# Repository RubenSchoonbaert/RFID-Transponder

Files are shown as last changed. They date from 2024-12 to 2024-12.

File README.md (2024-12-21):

# RFID-Transponder



Overview

This project is a compact and versatile PCB design featuring an RFID/NFC tag IC. It includes components for writing and managing data on the RFID tag, modern power input options, and flexible microcontroller integration.
Key Features

    RFID/NFC Tag Functionality
        Built-in RFID coil, designed using eDesignSuite by ST-Engineering.
        Integrated with the ST25DV04KC RFID/NFC Tag IC, offering:
            16 KB EEPROM for data storage.
            Communication via the I2C bus.
        Data can be written to the tag using external devices, such as smartphones with RFID capabilities.

    Data Storage Support
        Includes a Micro SD card slot for additional data storage.
        Utilizes a 74LVC125 IC for safe voltage level shifting between the 5V logic of the microcontroller and the 3.3V logic of the Micro SD card.

    Power Input
        Powered via a USB-C port delivering 5V.
        Configured with 1 kΩ resistors on the CC pins to ensure USB-C standard compliance.

    Flexible Microcontroller Integration
        Designed around the AtmegaXX08 series of microcontrollers, specifically the Atmega3208.
        Compatible with other ICs in the same series and package.

    Connectivity
        Provides connectors for UPDI and UART for programming and debugging.
        Optional GPIO breakout for additional interfacing needs.

Applications

    Use as an RFID/NFC tag in systems requiring dynamic, writable RFID data storage.
    Embedded designs requiring compact, integrated EEPROM and I2C functionality.
    Systems needing programmable and customizable tag IC solutions.

Schematic



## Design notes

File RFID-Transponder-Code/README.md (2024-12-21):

Application Note for RFID Transponder source code
Overview

This application demonstrates the integration of an ST25DV NFC/RFID Tag IC, an SD card module, and an Arduino-compatible microcontroller. It provides functionality for reading and writing data to the RFID tag, managing records on an SD card, and testing the system's integrated components such as LEDs and a piezo buzzer.
Features

    RFID Tag Management:
        Write a record to the ST25DV RFID Tag IC.
        Clear the last RFID entry.
        Detect new records from the RFID tag and log them on the SD card.

    SD Card Integration:
        Store and retrieve records from a text file (records.txt).
        Check for duplicate records before saving.
        Clear all records on the SD card.

    System Testing:
        Test the onboard piezo buzzer with preprogrammed melodies.
        Test the LED with blink functionality.

    Command Interface:
        Interactive commands via Serial Monitor for managing RFID and SD card operations.

Command Reference

    $printFile
    Prints all records stored on the SD card.

    $clearFile
    Clears all records in records.txt on the SD card.

    $clearRFID
    Writes a placeholder (!ignore) to the RFID tag to clear its last entry.

    $addRecord <record>
    Adds a new record to both the RFID tag and the SD card.

    $testBuzzer
    Plays a short melody on the piezo buzzer.

    $testLED
    Blinks the onboard LED to verify functionality.

System Workflow

    Setup:
        Initializes the ST25DV RFID Tag IC and the SD card module.
        Displays a splash screen with available commands.

    Serial Commands:
        Waits for user input via Serial Monitor.
        Executes the corresponding command and provides feedback through Serial output and the buzzer/LED.

    RFID Reading:
        Continuously reads the URI stored on the RFID tag.
        If a new record is detected and is not a duplicate, logs it to the SD card.

    Data Logging:
        Uses the SD card to store a persistent record of RFID tag data.
        Ensures duplicate records are not logged to prevent redundancy.

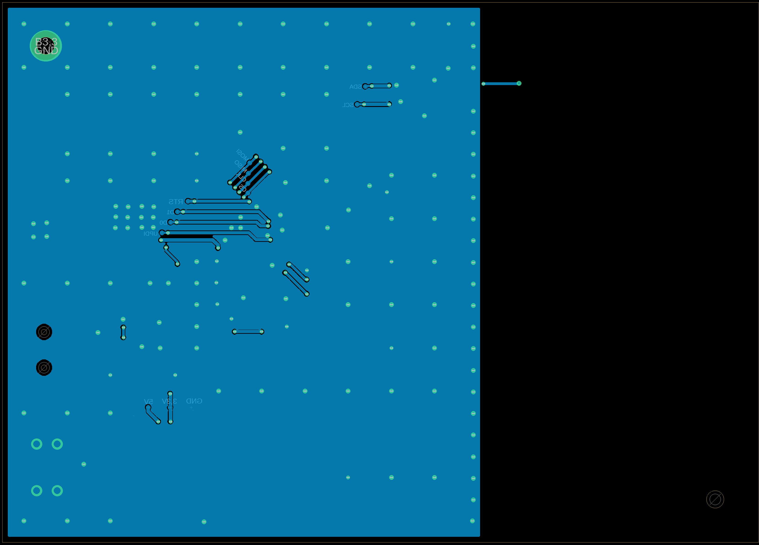
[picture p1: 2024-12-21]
RFID_Transponder/Bot-WP.png

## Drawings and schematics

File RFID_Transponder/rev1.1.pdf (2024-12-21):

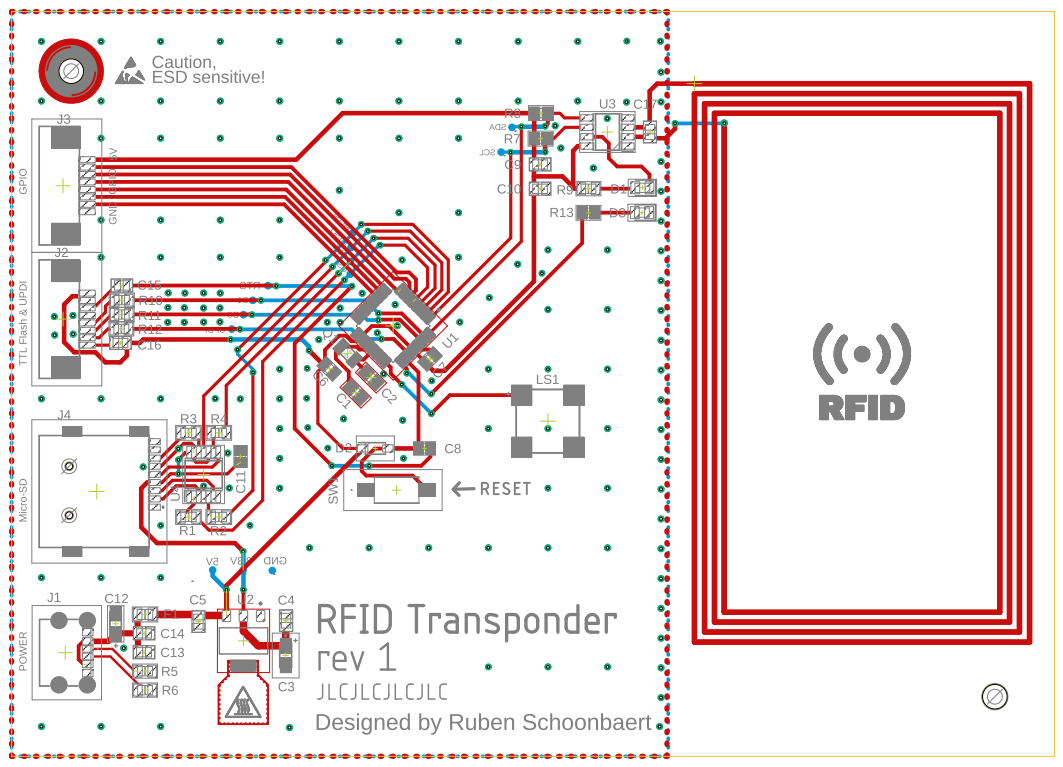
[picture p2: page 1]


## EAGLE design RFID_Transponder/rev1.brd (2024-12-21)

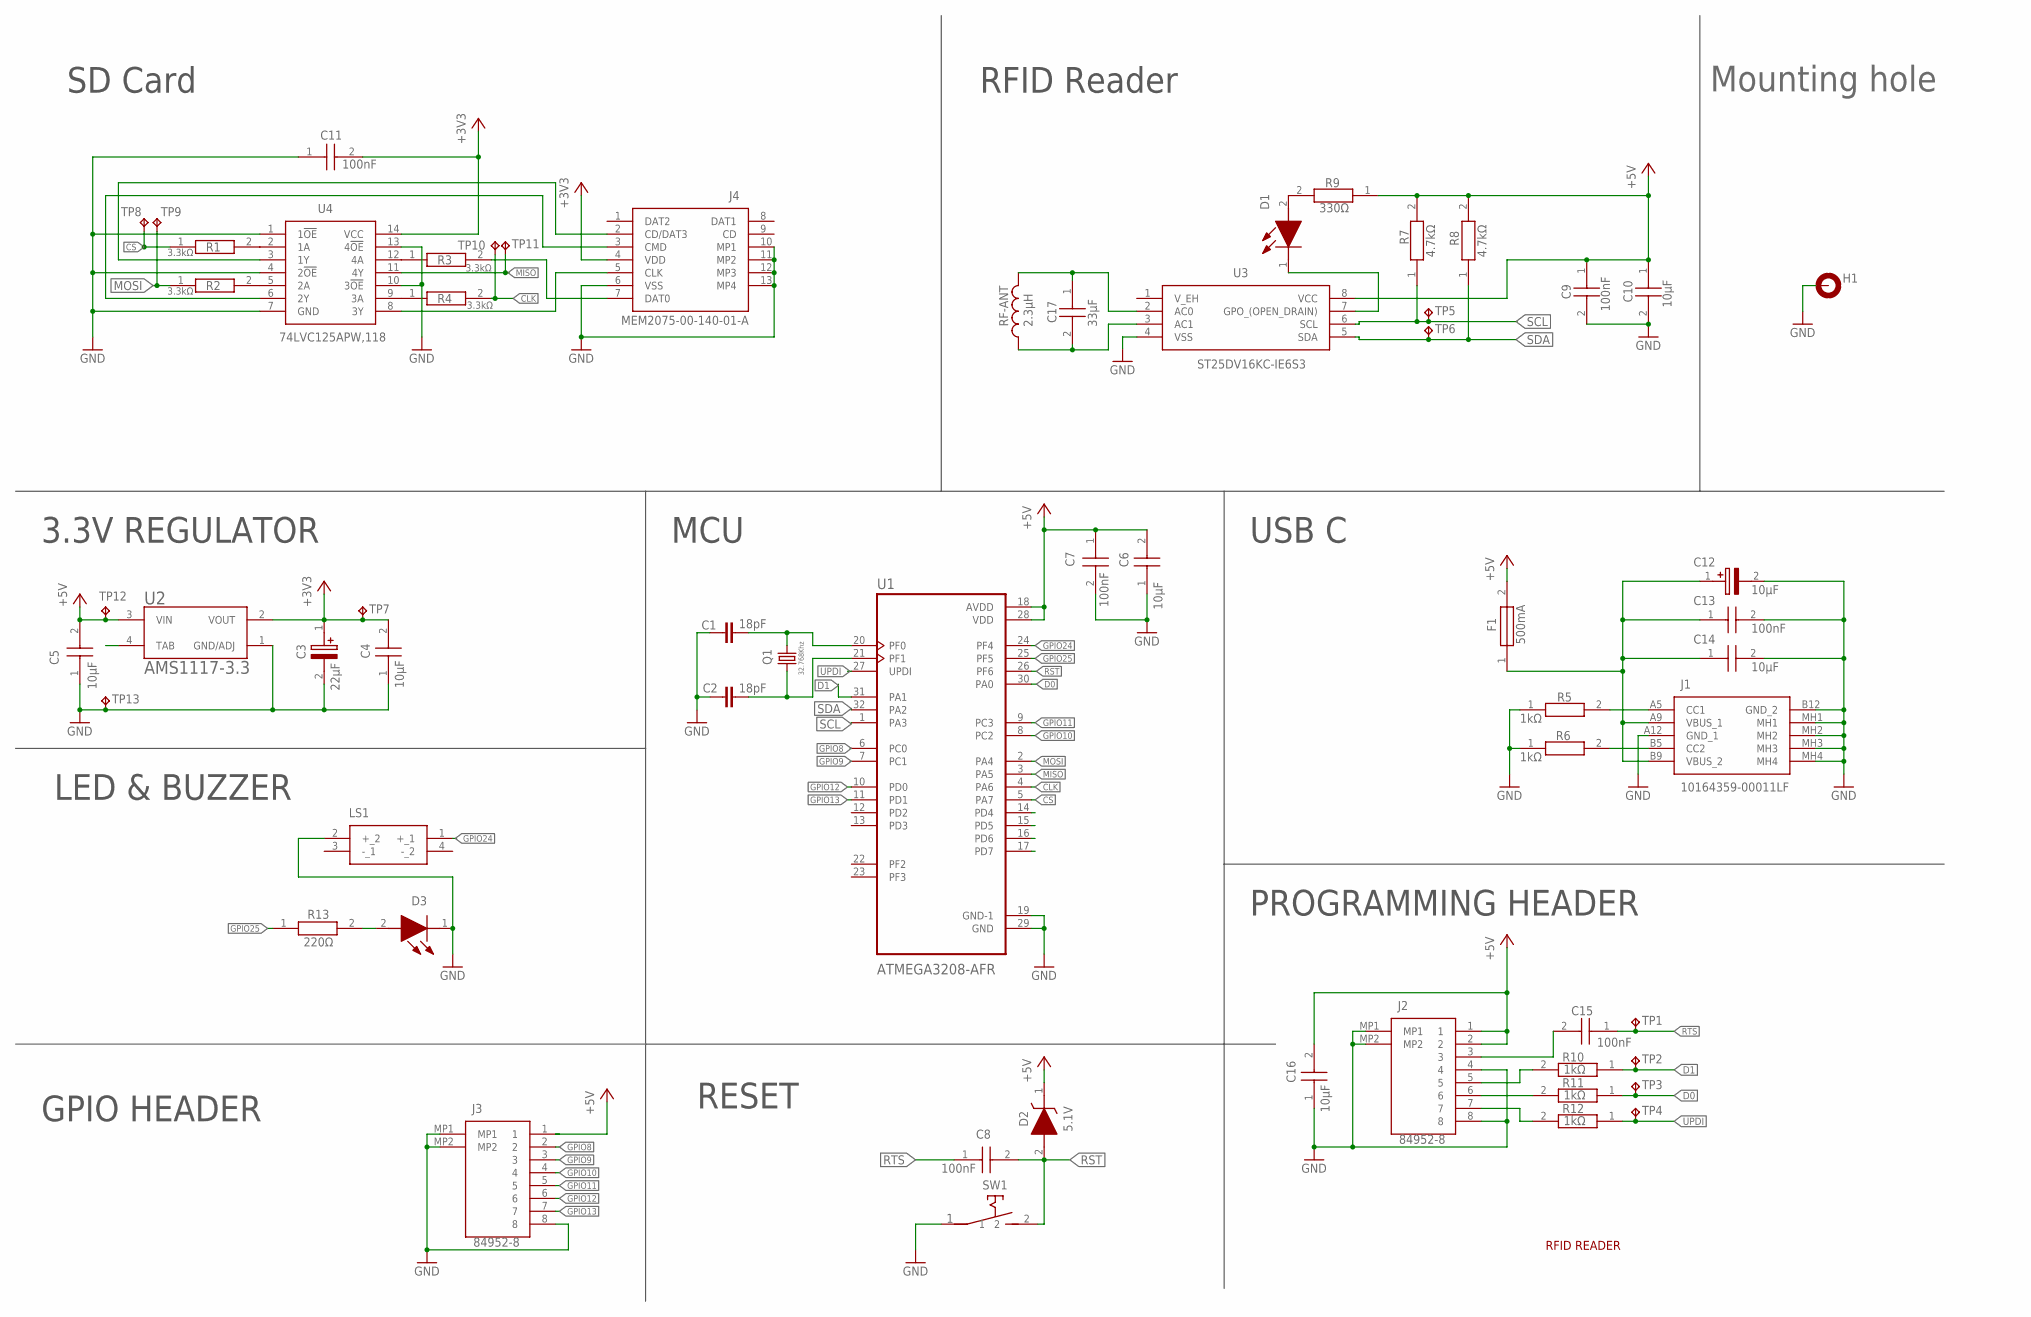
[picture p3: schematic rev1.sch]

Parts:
C1, C2: 18pF; C0805
C3: T491A226K004AT; T491A
C4, C5, C6, C10, C14, C16, C17: GRM21BR61C106KE15K; CAPC2012X145N
C7, C8, C9, C11, C13, C15: 08055C104KAT2A; CAPC2012X94N
C12: TAJA106K010YNJ; CAPPM3216X180N
D1, D3: SML-LXT0805GW-TR; LEDC2012X80N
D2: MMSZ5231B-7-F; SOD3716X145N
F1: SMD0805B050TF; FUSC2114X125N
H1: MOUNT-PAD-ROUND3.3; 3,3-PAD
J1: 10164359-00011LF; 1016435900011LF
J2, J3: 84952-8; 849528
J4: MEM2075-00-140-01-A; MEM20750014001A
LS1: CMT-8540S-SMT-TR
Q1: 32.768Khz; 3.2X1.5
R1, R2, R3, R4: CRCW08053K30FKEA; RESC2012X50N
R5, R6, R9, R10, R11, R12: RC0805FR-0710KL; RESC2012X60N
R7, R8, R13: RNCP0805FTD1K00; RESC2012X65N
SW1: TACTWITCH; PTS636SM50SMTRLFS
TP1, TP2, TP3, TP4, TP5, TP6, TP7, TP8, TP9, TP10, TP11, TP12, TP13: TPTP09R; TP09R
U1: ATMEGA3208-AFR; QFP80P900X900X120-32N
U2: AMS1117-3.3; SOT229P700X180-4N
U3: ST25DV16KC-IE6S3; SOIC127P600X175-8N
U4: 74LVC125APW,118; SOP65P640X110-14N
U$1: RF-ANT; RF_COIL

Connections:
+3V3: C3.1 (+), C4.2, C11.2, J4.4 (VDD), TP7.TP, U2.2 (VOUT), U4.14 (VCC)
+5V: C5.2, C6.2, C7.1, C9.1, C10.1, C16.2, D2.1 (K), F1.2, J2.1, J2.2, J3.1, R7.2, R8.2, R9.1, TP12.TP, U1.18 (AVDD), U1.28 (VDD), U2.3 (VIN), U3.8 (VCC)
CD$1: J4.2 (CD/DAT3), U4.3 (1Y)
CLK: R4.2, TP10.TP, U1.4 (PA6)
CS: R1.1, TP8.TP, U1.5 (PA7)
D0: R11.1, TP3.TP, U1.30 (PA0)
D1: R10.1, TP2.TP, U1.31 (PA1)
EN: C15.2, J2.3
GND: C1.1, C2.1, C3.2 (-), C4.1, C5.1, C6.1, C7.2, C9.2, C10.2, C11.1, C12.2 (-), C13.2, C14.2, C16.1, D3.1 (K), H1.B3,3, J1.A12 (GND_1), J1.B12 (GND_2), J1.MH1, J1.MH2, J1.MH3, J1.MH4, J2.4, J2.8, J2.MP1, J2.MP2, J3.8, J3.MP1, J3.MP2, J4.6 (VSS), J4.10 (MP1), J4.11 (MP2), J4.12 (MP3), J4.13 (MP4), LS1.2 (+_2), R5.1, R6.1, SW1.1, TP13.TP, U1.19 (GND-1), U1.29 (GND), U2.1 (GND/ADJ), U3.4 (VSS), U4.1 (1!OE), U4.4 (2!OE), U4.7 (GND), U4.10 (3!OE), U4.13 (4!OE)
GPIO8: J3.2, U1.6 (PC0)
GPIO9: J3.3, U1.7 (PC1)
GPIO10: J3.4, U1.8 (PC2)
GPIO11: J3.5, U1.9 (PC3)
GPIO12: J3.6, U1.10 (PD0)
GPIO13: J3.7, U1.11 (PD1)
GPIO24: LS1.1 (+_1), U1.24 (PF4)
GPIO25: R13.1, U1.25 (PF5)
MISO: TP11.TP, U1.3 (PA5), U4.11 (4Y)
MOSI: R2.1, TP9.TP, U1.2 (PA4)
unnamed: C1.2, Q1.2, U1.20 (PF0)
unnamed: C2.2, Q1.1, U1.21 (PF1)
unnamed: J4.5 (CLK), U4.8 (3Y)
unnamed: J4.7 (DAT0), R3.2
unnamed: J1.A5 (CC1), R5.2
unnamed: D1.1 (K), U3.7 (GPO_(OPEN_DRAIN))
unnamed: J4.3 (CMD), U4.6 (2Y)
unnamed: R1.2, U4.2 (1A)
unnamed: R2.2, U4.5 (2A)
unnamed: R3.1, U4.12 (4A)
unnamed: R4.1, U4.9 (3A)
unnamed: J1.B5 (CC2), R6.2
unnamed: D1.2 (A), R9.2
unnamed: C12.1 (+), C13.1, C14.1, F1.1, J1.A9 (VBUS_1), J1.B9 (VBUS_2)
unnamed: D3.2 (A), R13.2
unnamed: J2.7, R12.2
unnamed: C17.2, U3.3 (AC1), U$1.P$3 (1)
unnamed: C17.1, U3.2 (AC0), U$1.P$1 (2)
unnamed: J2.5, R10.2
unnamed: J2.6, R11.2
RST: C8.2, D2.2 (A), SW1.2, U1.26 (PF6)
RTS: C8.1, C15.1, TP1.TP
SCL: R7.1, TP5.TP, U1.1 (PA3), U3.6 (SCL)
SDA: R8.1, TP6.TP, U1.32 (PA2), U3.5 (SDA)
TAB: U2.4 (TAB)
UPDI: R12.1, TP4.TP, U1.27 (UPDI)

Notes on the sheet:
22µF
10µF
100nF
5.1V
3.3kΩ
1kΩ
500mA
4.7kΩ
330Ω
RESET
3.3V REGULATOR
PROGRAMMING HEADER
USB C
MCU
33µF
2.3µH
SD Card
RFID Reader
GPIO HEADER
RFID READER
LED & BUZZER
220Ω
Mounting hole

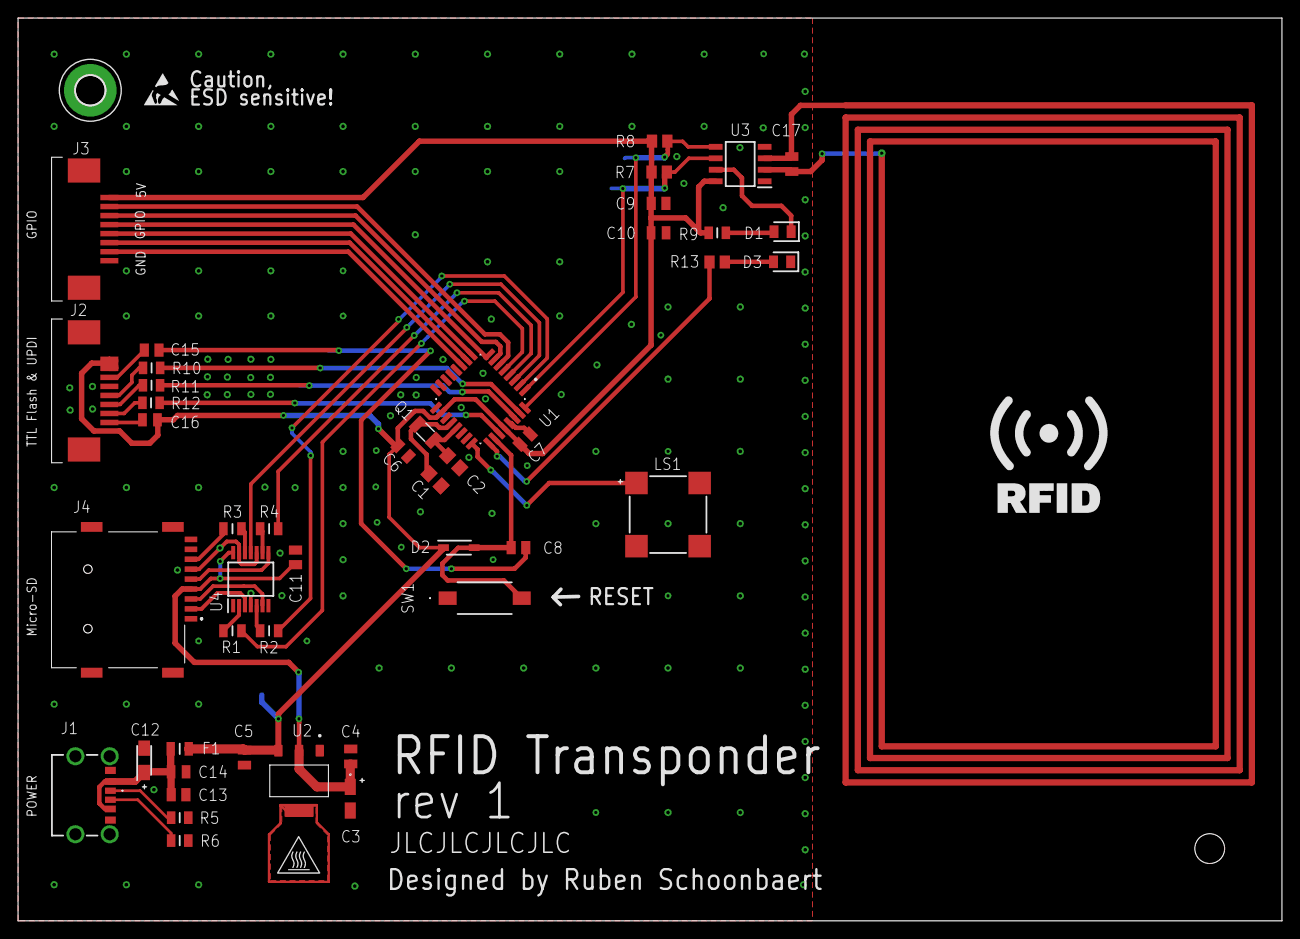
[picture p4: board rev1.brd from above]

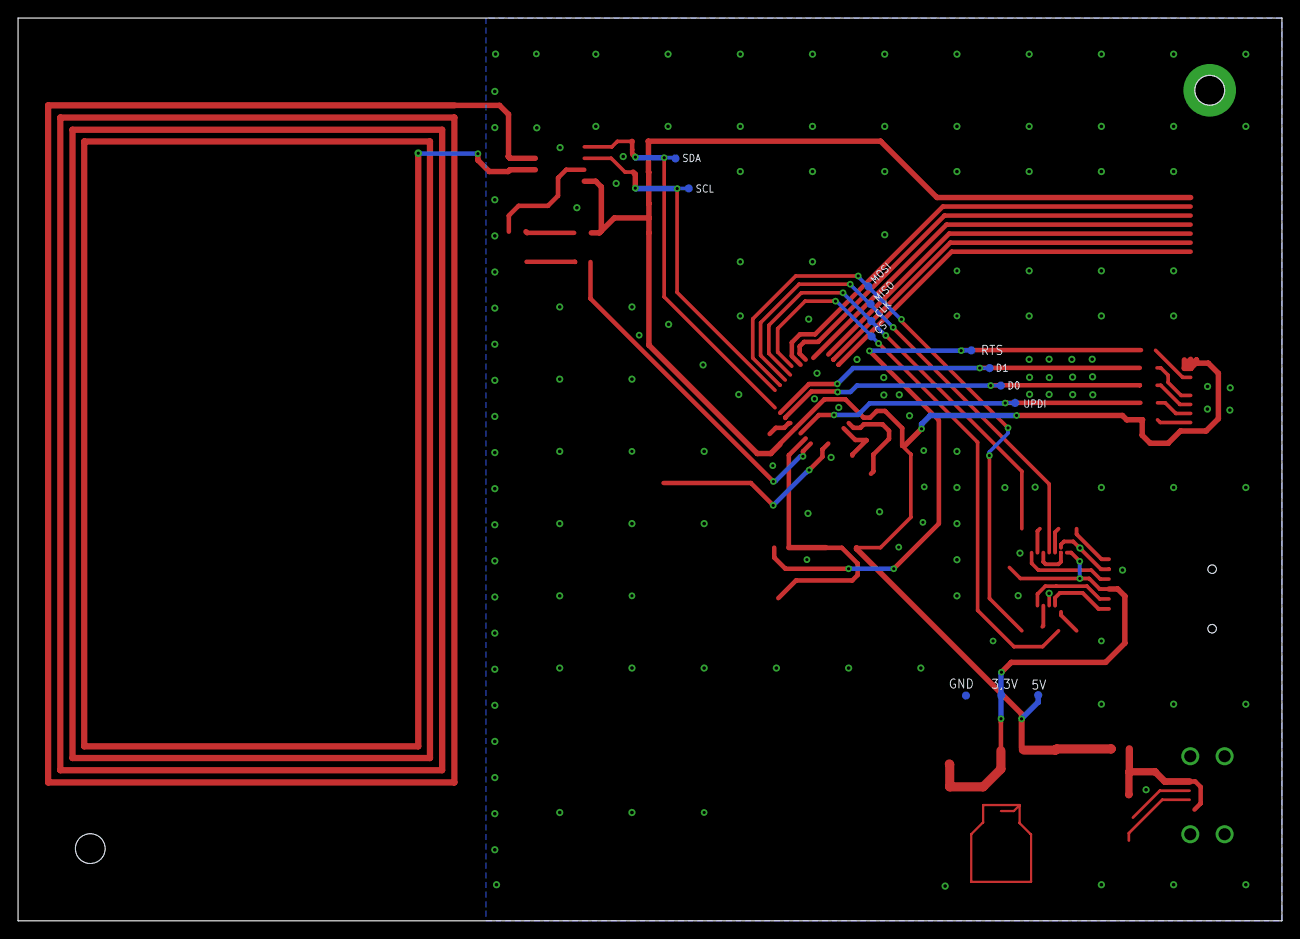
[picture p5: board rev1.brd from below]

Board: 2 copper layers, 140.0 x 100.0 mm, 60 parts (13 on the bottom side), 44 nets.

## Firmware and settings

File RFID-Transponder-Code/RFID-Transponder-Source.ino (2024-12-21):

#include "ST25DVSensor.h"
#include <SPI.h>
#include <SD.h>

#if defined(ARDUINO_B_L4S5I_IOT01A)
  #define GPO_PIN PE4
  #define LPD_PIN PE2
  #define SDA_PIN PB11
  #define SCL_PIN PB10
  #define WireNFC MyWire
  TwoWire MyWire(SDA_PIN, SCL_PIN);
  ST25DV st25dv(12, -1, &MyWire);
#else
  #define DEV_I2C         Wire
  ST25DV st25dv(12, -1, &DEV_I2C);
#endif
String last_read;
bool cleared = false;
const int chipSelect = 7;

void beep(int pitch, int duration, int loudness){
  tone(24, pitch, loudness);
  delay(duration);
  noTone(24);
  delay(10);
}

void clearFile(const char* filename) {
  if (SD.begin(chipSelect)) {
    // Open the file in write mode without appending
    File myFile = SD.open(filename, FILE_WRITE | O_TRUNC);
    
    if (myFile) {
      myFile.close();
      Serial.println("File cleared!");
    }
  }
}

void printLine(){
  for(int i = 0; i < 50; i++){
    Serial.print('-');
  }
  Serial.println();
}

void printStart(){
  Serial.println(F("         ╔═══╦═══╦══╦═══╗"));
  Serial.println(F("         ║╔═╗║╔══╩╣╠╩╗╔╗║"));
  Serial.println(F("         ║╚═╝║╚══╗║║─║║║║"));
  Serial.println(F("         ║╔╗╔╣╔══╝║║─║║║║"));
  Serial.println(F("         ║║║╚╣║──╔╣╠╦╝╚╝║"));
  Serial.println(F("         ╚╝╚═╩╝──╚══╩═══╝"));  
  printLine();
  Serial.println(F("By Ruben Schoonbaert"));
  Serial.println(F("Written 29/12/2023"));
  printLine();
  delay(1000);
  Serial.println(F("COMMANDS:"));
  Serial.println(F("$printFile -> prints all records on the SD card"));
  Serial.println(F("$clearFile -> clears all records on the SD card"));
  Serial.println(F("$clearRFID -> removes last entry from RFID tag"));
  Serial.println(F("$addRecord <record> -> Adds new record to SD & RFID Tag"));
  Serial.println(F("$testBuzzer -> Tests integrated piezo buzzer"));
  Serial.println(F("$testLED -> Tests integrated LED"));
  printLine();
}

void printFile(const char* filename) {
  if (SD.begin(chipSelect)) {
    // Open the file in read mode
    File myFile = SD.open(filename, FILE_READ);
    printLine();
    Serial.println(F("    Printing SD-Card content    "));
    printLine();
    if (myFile) {
      while (myFile.available()) {
        Serial.write(myFile.read());
      }
      
      myFile.close();
      printLine();
    } else {
      Serial.println(F("Error opening file for reading."));
      digitalWrite(25, HIGH);
    }
  }
}

bool isDuplicate(const char* filename, const String& newString) {
  File file = SD.open(filename);
  if (file) {
    while (file.available()) {
      String line = file.readStringUntil('\n');
      line.trim();
      if (line.equals(newString)) {
        file.close();
        return true; // Duplicate found
      }
    }
    file.close();
  }
  return false; // No duplicate found
}

void addRecord(String record){
  const char uri_write_protocol[] = URI_ID_0x01_STRING;
  if(st25dv.writeURI(uri_write_protocol, record, "")) {
    Serial.println(F("Write to RFID Tag failed!"));
    digitalWrite(25, HIGH);
    while(1);
  } else {
    if(record != "!ignore"){
    Serial.print(F("Written : \""));
    Serial.print(record);
    Serial.print(F("\" to RFID tag succesfully"));
    Serial.println();
    }
  }
}

void setup() {
  Serial.begin(9600);
  pinMode(24, OUTPUT);
  pinMode(25, OUTPUT);
  digitalWrite(25, HIGH);
  printStart();
  // The wire instance used can be omitted in case you use default Wire instance
  if(st25dv.begin() == 0) {
    Serial.println(F("System Init done!"));
    beep(2000, 100, 50);
  } else {
    Serial.println("System Init failed!");
    digitalWrite(25, HIGH);
    while(1);
  }
  delay(500);
  digitalWrite(25, LOW);
}

void loop() {  
  String uri_read;
   if (Serial.available() > 0) {
    String command = Serial.readStringUntil('\n');
    command.trim();
    
    if (command.equals("$clearFile")) {
      clearFile("records.txt");
      cleared = true;
      beep(2000, 100, 50);
      return;
    } else if (command.equals("$printFile")){
       beep(2000, 100, 50);
      printFile("records.txt");
    } else if (command.startsWith("$addRecord ")) {
      // Extract the record from the command
      String recordToAdd = command.substring(11); 
      // Add the record to the file
      addRecord(recordToAdd);
    } else if (command.equals("$clearRFID")){
       addRecord("!ignore");
       Serial.println(F("Cleared RFID"));
         beep(2000, 100, 50);
    } else if (command.equals("$testLED")){
      bool state = false;
      for(int i = 0; i<10; i++){
        digitalWrite(25, state);
        state = !state;
        delay(100);
      }
    }
     else if (command.equals("$testBuzzer")){
     int melody[] = {262, 330, 392, 523, 392, 330, 262, 196, 262};
     for (int i = 0; i < sizeof(melody) / sizeof(melody[0]); i++) {
      delay(10);
      beep(melody[i], 200, 100);
     }

    } else {
      Serial.println("unrecognised command!");
      beep(500, 500, 500);
    }
  }
  
  if(st25dv.readURI(&uri_read)) {
    Serial.println("Read failed!");
    digitalWrite(25, HIGH);
    while(1);
  } 
  if(uri_read != last_read){
     if (SD.begin(chipSelect)) {
      if(uri_read.startsWith("www.")){
        uri_read = uri_read.substring(4);
      }
      else if(uri_read.startsWith("http://www.")){
        uri_read = uri_read.substring(11);
      }
      else if(uri_read.startsWith("http://")){
        uri_read = uri_read.substring(7);
      }
      else if(uri_read.startsWith("https://")){
        uri_read = uri_read.substring(8);
      }
      if(uri_read != "!ignore"){
        // Check if the last line of the file is the same as the string
        if (!isDuplicate("records.txt", uri_read)) {
          if(!cleared){
            Serial.print(F("New record detected = "));
          } else {
            Serial.print(F("current RFID record = "));
          }
          cleared = false;
          Serial.print(uri_read);
          Serial.println();
          
          File myFile = SD.open("records.txt", FILE_WRITE);
          if (myFile) {
            // Write to the file
            myFile.println(uri_read);
            // Close the file
            myFile.close();
            delay(100);
            beep(800, 100, 50);
            delay(10);
            beep(1000, 100, 50);
           }
          }
        }
       last_read = uri_read;
     }
  }
  delay(500);
  digitalWrite(25, LOW);
} 

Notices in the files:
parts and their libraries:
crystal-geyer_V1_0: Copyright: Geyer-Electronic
